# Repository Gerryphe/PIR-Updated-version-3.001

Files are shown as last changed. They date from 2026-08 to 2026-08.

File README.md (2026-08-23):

1. install node js (v9.9.0) https://nodejs.org
2. restart pc
3. install gulp. Type in console npm install -g gulp
4. restart pc
5. open console in project folder
6. npm i - install all modules from package.json
7. index.js file from project foder copy to node_modules\gulp-filelist\
8. gulp clean - clr destination folder
9. gulp build - build project 
10. gulp buildGz - build project with Gzip compression 
11. dest folder - compressed web interface
11. dest\bin folder - binary files for mcu
12. dest\bin\http_serv_fse.cpp - copy this file to project folder, contains all web interface

1. install node js (v10.1.0) https://nodejs.org
2. restart pc
3. install gulp. Type in console npm install -g gulp
4. restart pc
5. open console in project folder
6. npm i - install all modules from package.json
7. index.js file from project foder copy to node_modules\gulp-filelist\
8. gulp clean - clr destination folder
9. gulp build - build project 
10. gulp buildGz - build project with Gzip compression 
11. dest folder - compressed web interface
11. dest\bin folder - binary files for mcu
12. dest\bin\http_serv_fse.cpp - copy this file to project folder, contains all web interface

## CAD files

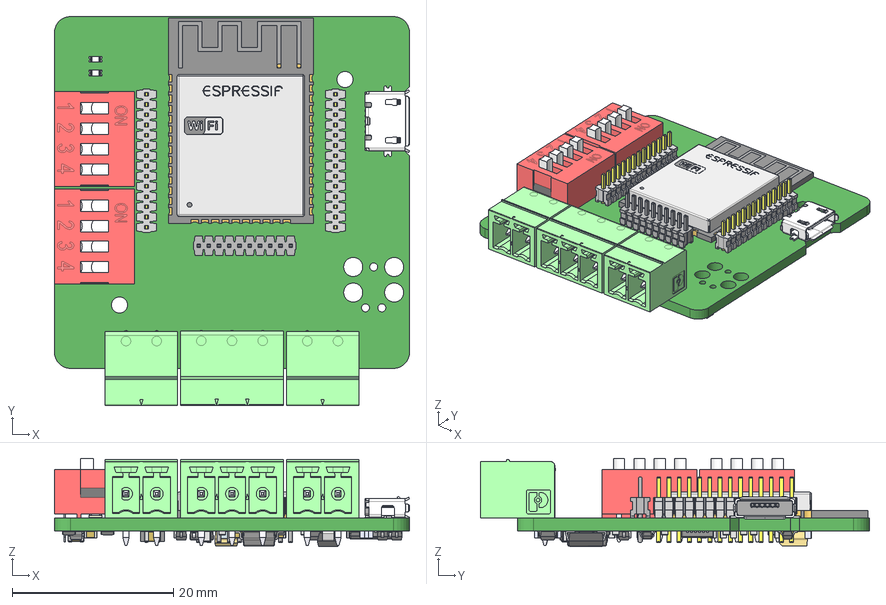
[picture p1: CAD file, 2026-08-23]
1-10VPIR_V1.0/1-10V_PIR_V1.0.step
44.1 x 48.3 x 11.0 mm
T-1M6-10-02-S
TMS-110-S_header
pcb
pads
antenna
logo
SW3dPS-SOD-323 x 4
USB3085-HOUSING
USB3085-SHELL
cap0805 2x1.25x1.35 x 3
User Library-RES_0603L_RES_0603_Lead_1 x 50
User Library-RES_0603L_RES_0603_Body_1 x 25
SW3dPS-LED SMD0603 x 2
T-1M6-14-02-S x 2
TMS-114-S_header x 2
Notch
Silicon Lab Logo Yury
PinsArrayL
PinsArrayR
BODY_MF06A
LEAD_MF06A x 6
User Library-sot143
SW3dPS-Maxim_SOIC8
DS-4 x 2
BAT54 x 2
Pins
BLM18AG601SN1D
0ZCJ0010FF2E--3DModel-STEP-56544
DO-214AC (SMA)
cap0603 1.6x0.8x0.9 x 13
Tant cap CaseB_3528-21

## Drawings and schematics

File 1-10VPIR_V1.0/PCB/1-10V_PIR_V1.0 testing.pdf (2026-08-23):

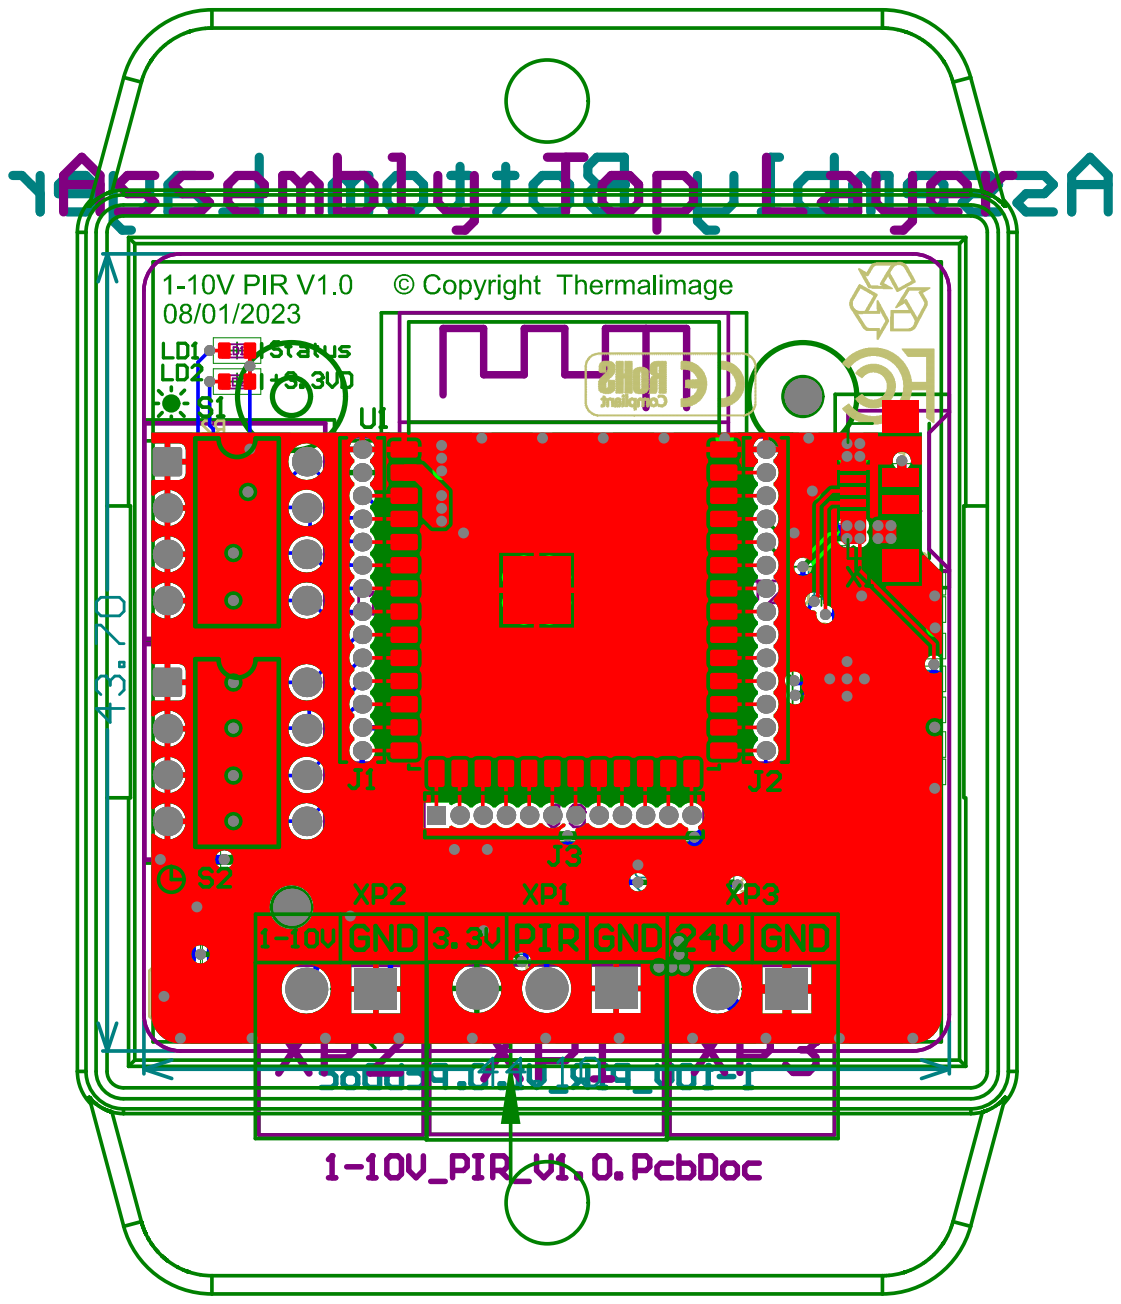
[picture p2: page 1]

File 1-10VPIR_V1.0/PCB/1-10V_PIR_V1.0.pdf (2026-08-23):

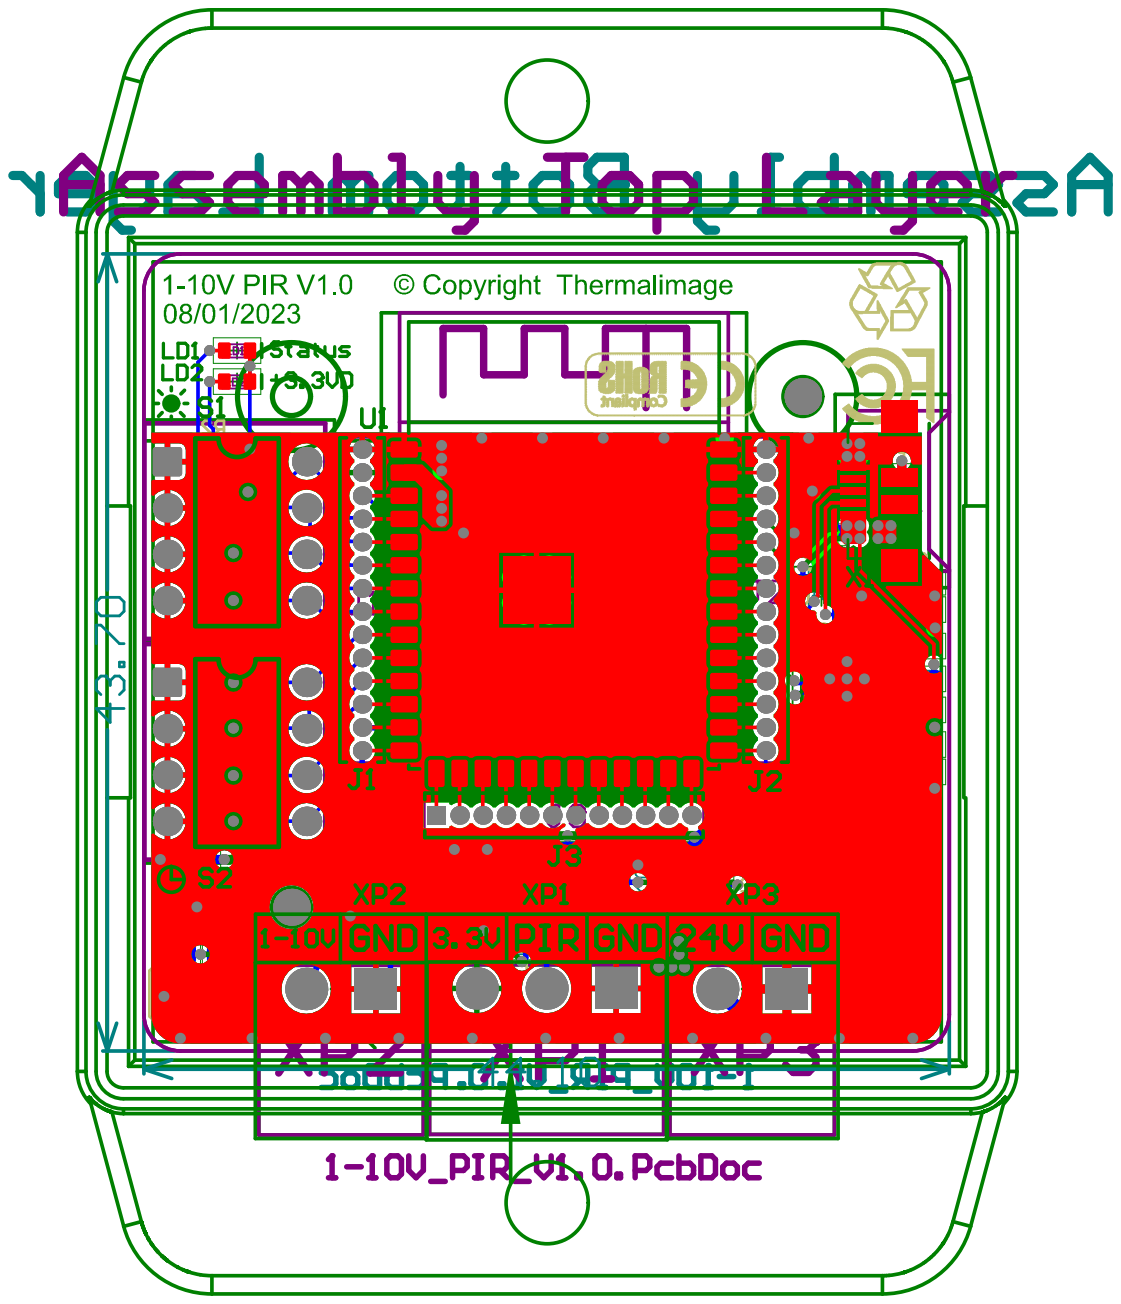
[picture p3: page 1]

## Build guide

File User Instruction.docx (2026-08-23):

# quebec-1-10v-pir

## Introduction

There are two variants of this product one is for prototyping which has the USB to serial chip and can be flash using the USB. The other one is production one that needs tag-connect and programmer. (check, Figs 1,2 and 3)

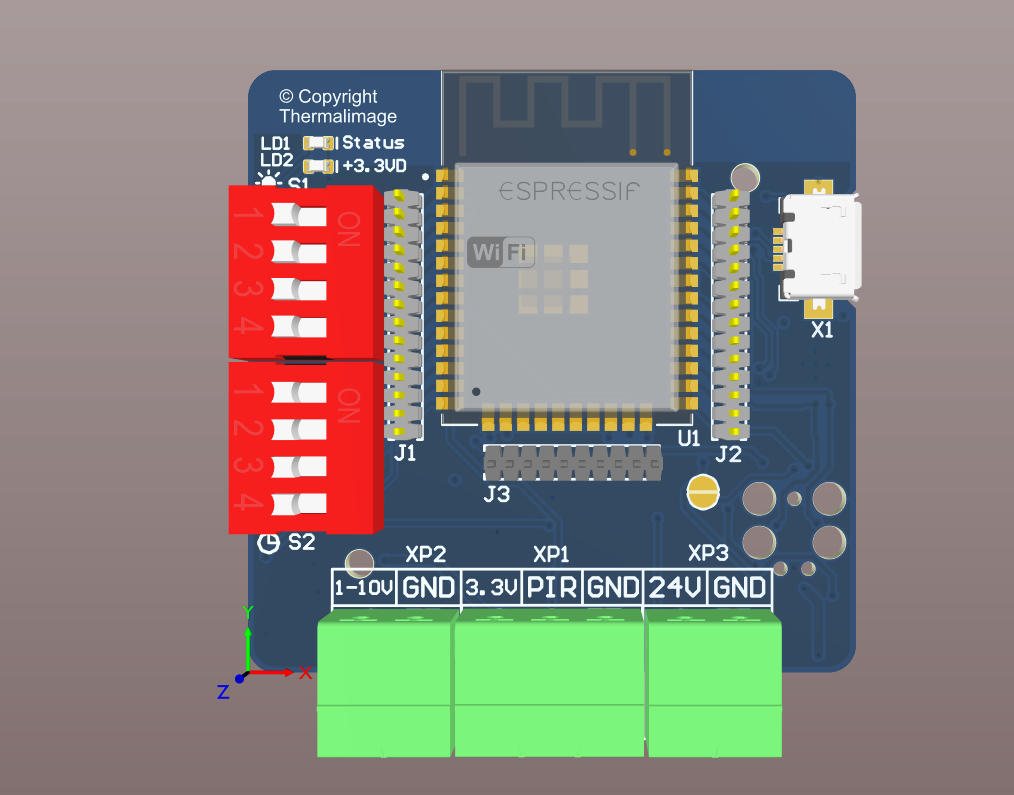
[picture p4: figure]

Figure 1: Top view prototype and Production.

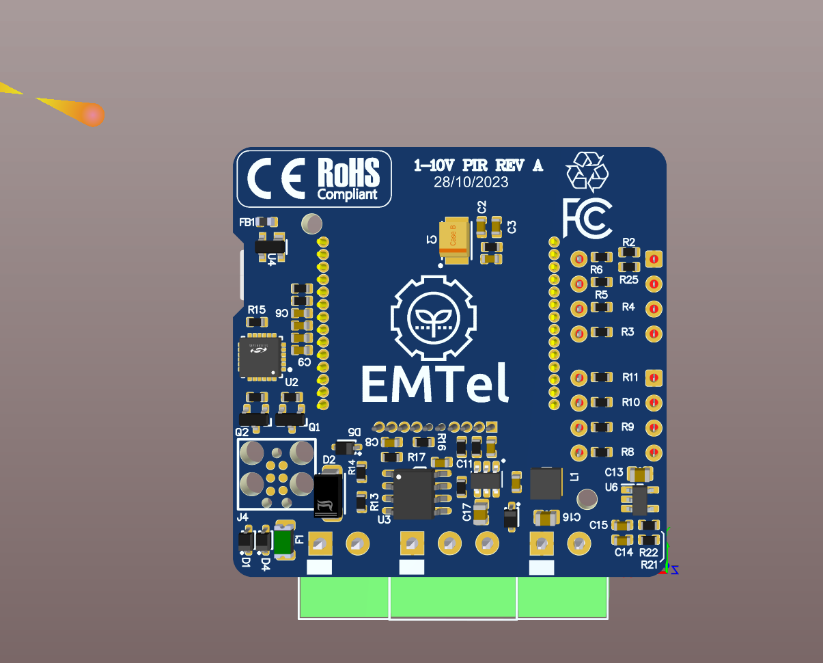
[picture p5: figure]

Figure 2: prototype bottom view.

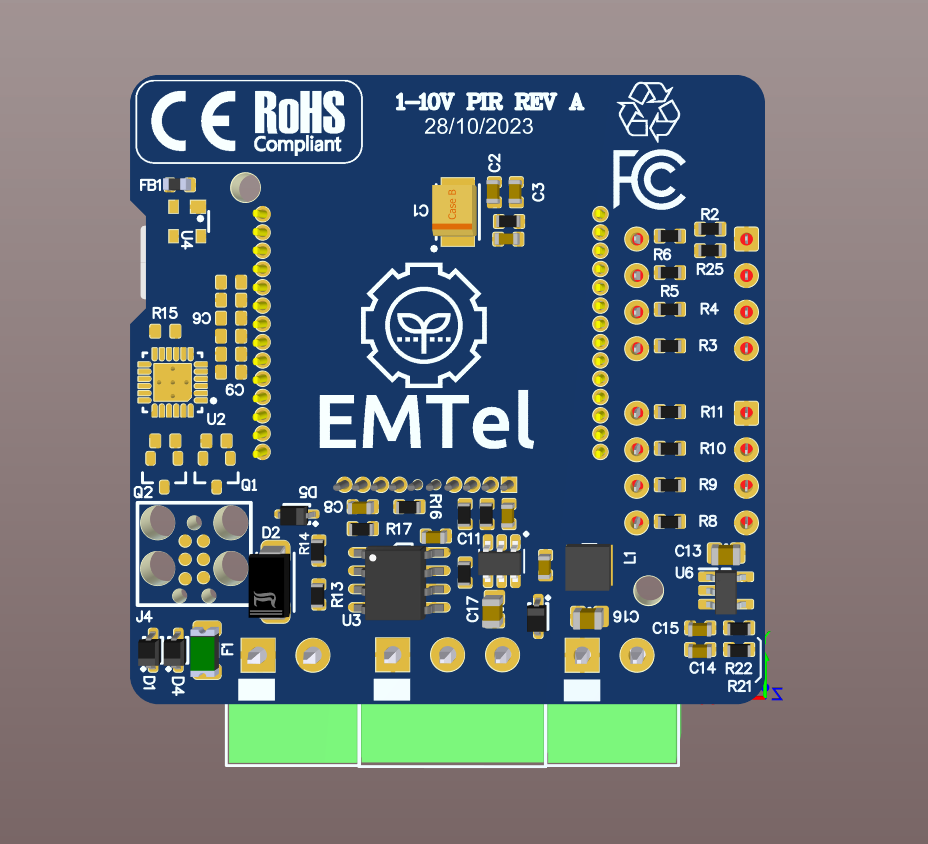
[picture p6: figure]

Figure 3: bottom view of production.

## Connections and Dip switches

There are 2 dip switches on the board for adjusting delay and adjusting dimming.

There is one connector for LED driver, one for PIR sensor and the other one for 24V input, note that the device will power on by USB but for LED driver to work we need 24V input.

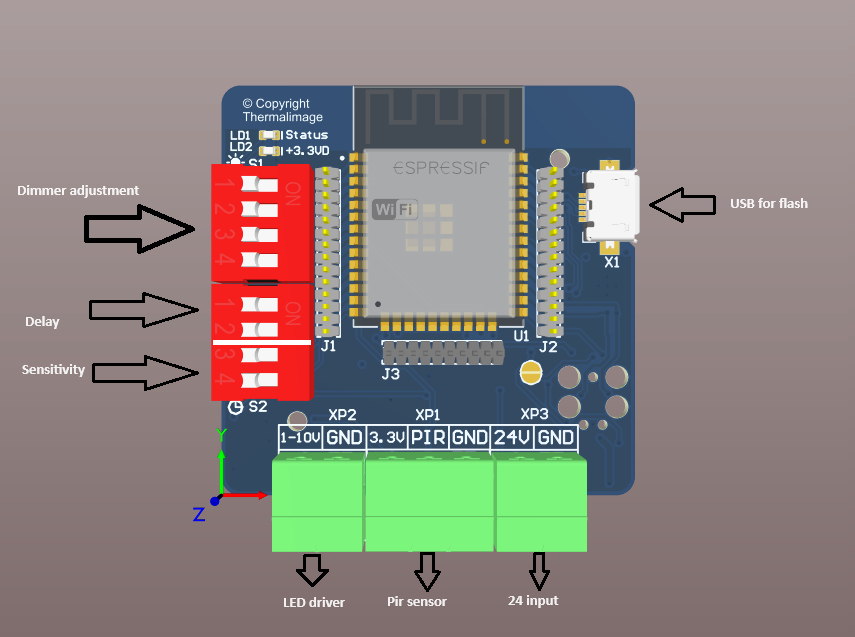
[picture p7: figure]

Figure 4: Connections and dip switch on the board

## Flashing the device (prototype)

Current build is prototype build which does not need tag connect and can be flash directly using USB.

After connecting device to USB, a new serial port (COM port) appear on device manager, the number of appear port can be different (Fig,5 )

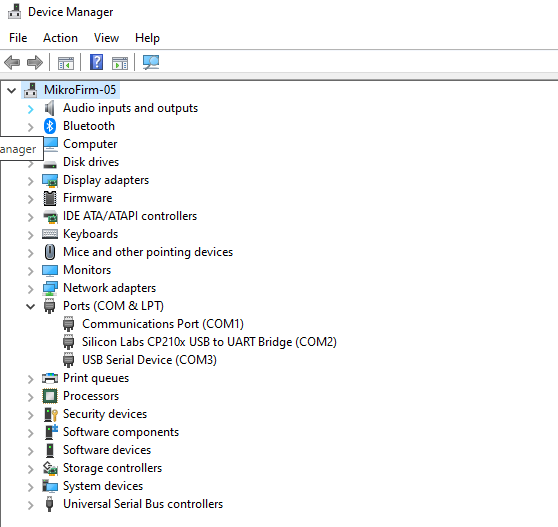
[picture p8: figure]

Figure 5: Silicon Labs CP210x COM2

Now open “flash_download_tool_3.9.5.exe” (from flash folder) and select ESP 32, the following screenshot.

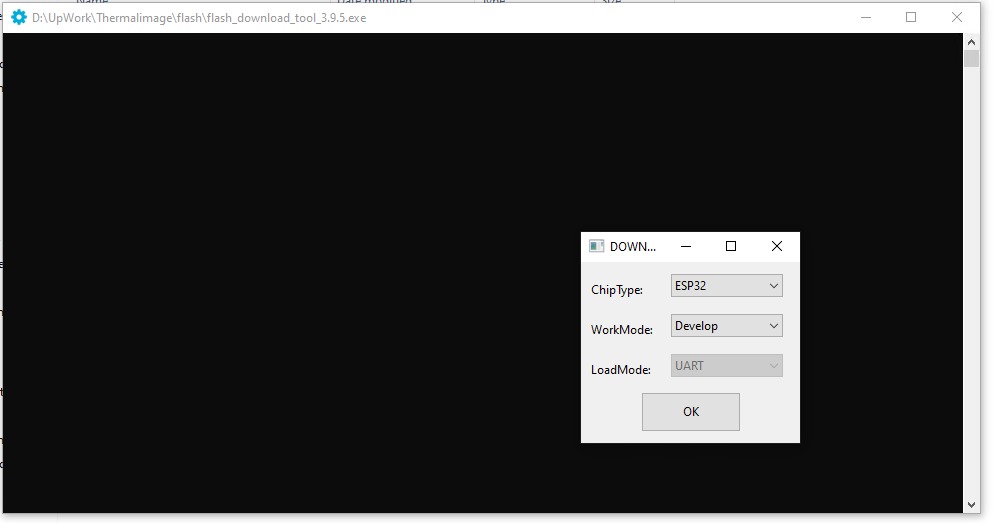
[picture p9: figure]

The set up as the following figure and select right com port.

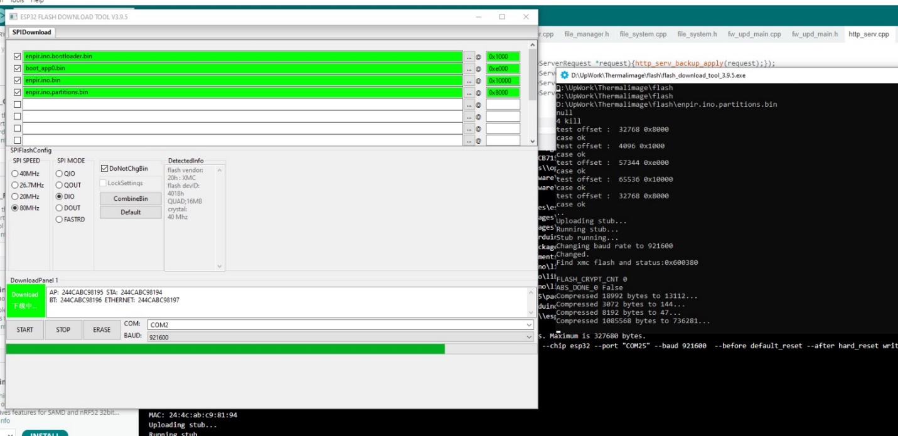
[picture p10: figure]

After flashing follow the these steps.

The first step is to connect to the device.

Devices advertise itself as an access point and name (SSID) is
ENPIR-<mac address>

Password: enco212345

After connection go to a browser and the address is 192.168.1.1

Enter ‘admin’ as username and ‘admin’ as password (Fig, 1).

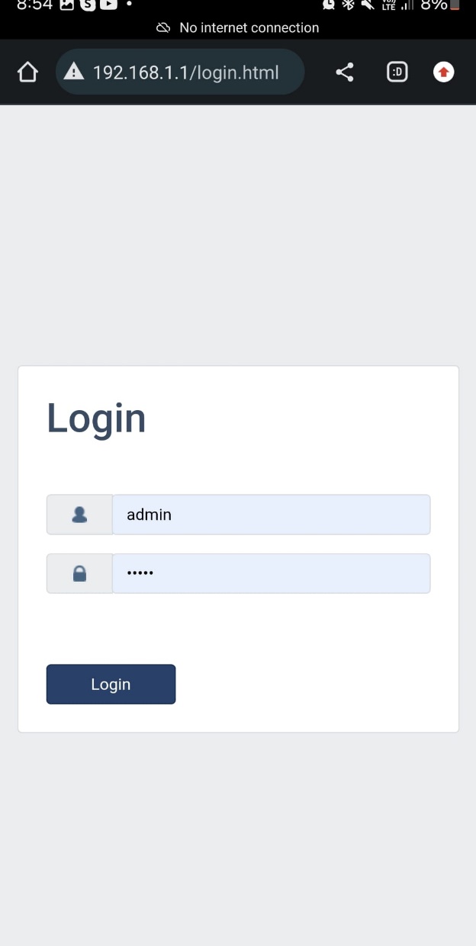
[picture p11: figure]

Figure 6: connect to access point and login.

Then from the hamburger button, select WIFI, enable STA mode and scan for the WIFI SSID and enter the password. After connection you will see the IP address associated to the device by DHCP (Fig,2).

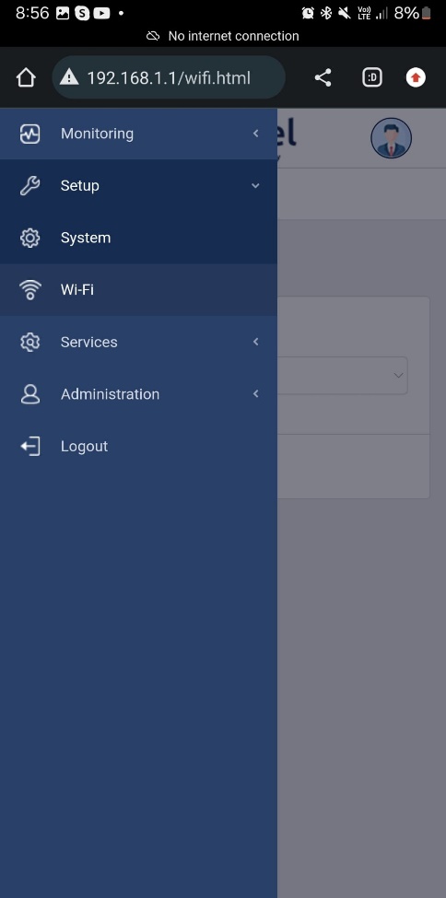
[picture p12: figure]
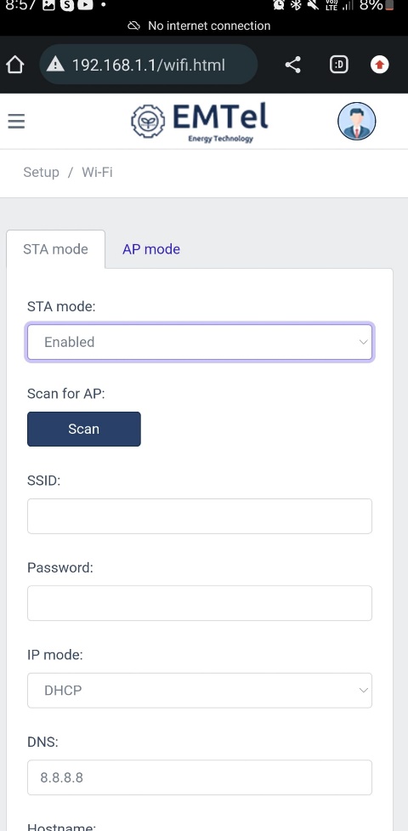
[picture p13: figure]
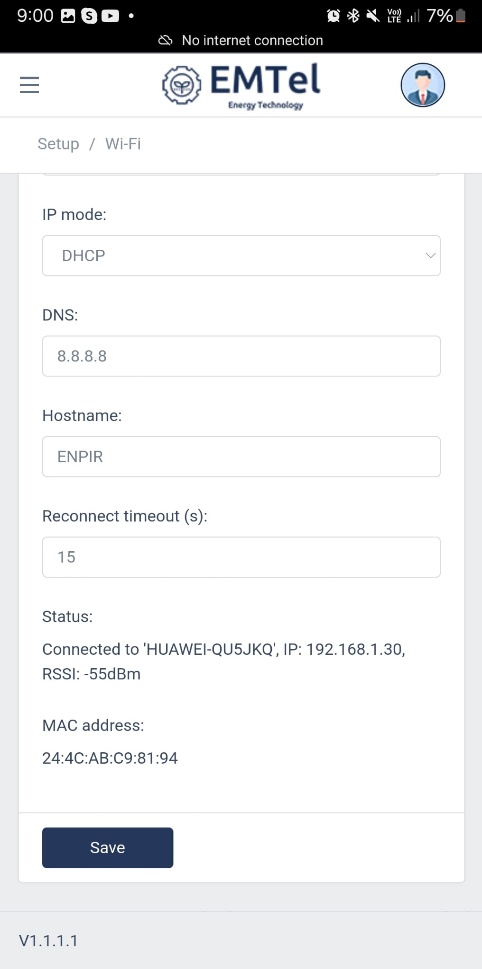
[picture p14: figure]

Figure 7: setup WIFI

Now the device can be accessed using this IP with a computer or a mobile on the same network.

## 1-10 PIR Dimming control Sensor

For setting up the 1-10, please go to setup/system and enable Display and by default it shows 25 to 100, and other values can be selected by using dip switch on the board.

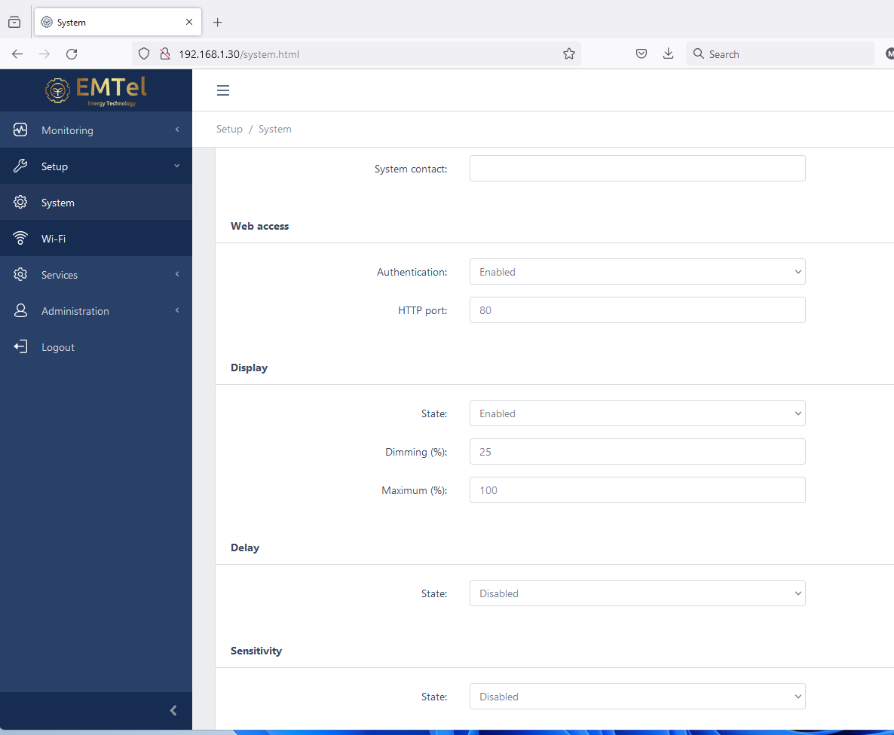
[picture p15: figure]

When the device triggers (PIR sensor activated) the voltage level of driver goes to the maximum that is setup in the web UI considering the position of 4-bit dip switch (refer to Fig 4).

The applied voltage value is based on the diffidence between maximum and minimum, divided by dip switch value

Example:

Maximum: 100% (10V)

Minimum: 25% (2.5V)

(S1) 4-bit dip position (1,2,3,4) 1111 (see Fig, 8)

The applied value will be 10V during activation.

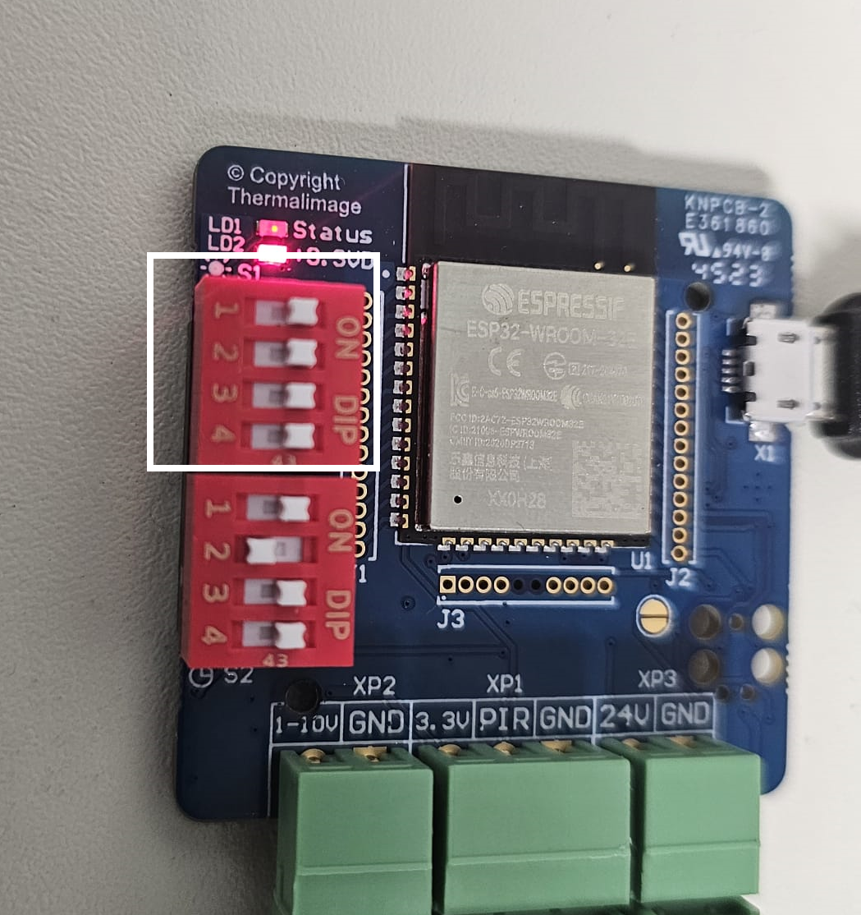
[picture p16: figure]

Figure 8: Position of dip switch for 1111

(S1) 4-bit dip position (1,2,3,4) 0000

The applied value will be same as minimum during activation.

S1) 4-bit dip position (1,2,3,4) XXXX (see Fig, 8)

XXXX should be turned to binary.

The applied value will be same as minimum + 1/15 (maximum – minimum)x(XXXX) during activation.

Note 1: that if the delay disabled the output of LED driver will be 0.

Note 2: The minimum dim allowed is 10% and the minimum and maximum should have at least 20% difference.

Connect the LED driver and test.

## 1-10 PIR delay

When the delay is enabled, after activation and deactivation timer will start.

If all delay switch is on 11 it is full delay set in the web portal and if

XX the results

(XX+1)/4 x (time set in the web portal).

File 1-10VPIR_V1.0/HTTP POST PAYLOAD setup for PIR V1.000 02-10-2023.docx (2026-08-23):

{

"Monitor":{

"DeviceInfo":{

"DeviceMod":"PIR-V1.000",

"DeviceName":"As per name input in setup",

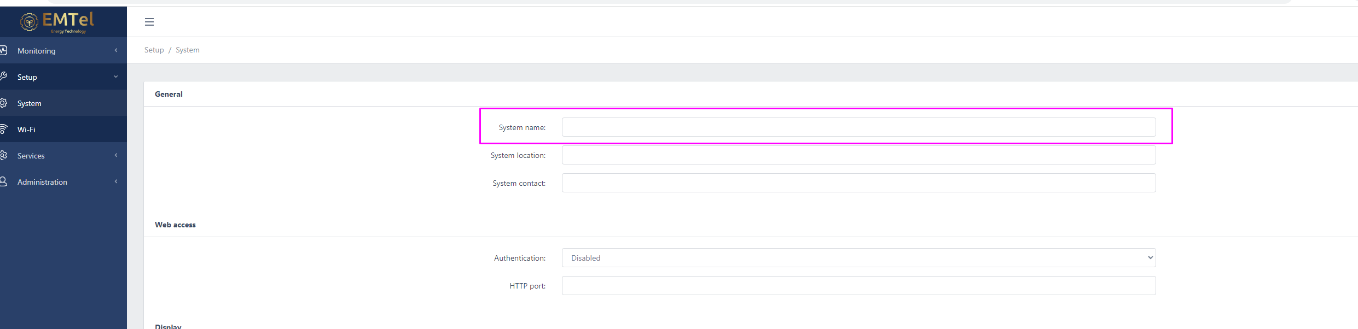
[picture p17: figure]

"ID":"24:0A:C4:AF:DF:98", we need to be able to assign our own mac id

"MainAppVer":"1.1.1.1", from the device

"MainBootVer":"1.1.1.1", from the device

"WiFi":{

"Ver":"1.3.5.8", from the device

"AP":{

"MAC":"24:0A:C4:AF:DF:99",

"State":1,

"Signal":19.5

},

"STA":{

"MAC":"24:0A:C4:AF:DF:98",

"State":1,

"Signal":-40

}

}

},

"CH":{

"CH1":{

"status":0, enabled = 1 or disabled = 0

"description":"Max Output",

"MO":100, As per setup This is in %

},

"CH2":{

"status":0, enabled = 1 or disabled = 0

"description":"Dimming",

"DI":25, As per setup this is in %

"DC":96, counter of cycles

"DA":0, dimming active = 1 dimming in standby = 0

},

"CH3":{

"status":0, enabled = 1 or disabled = 0

"description":"Time Out",

"TO":20, As per setup this is displayed in min

},

"CH4":{

"status":0, enabled = 1 or disabled = 0

"description":"Sensitivity",

"SY":85,As per setup This is in %

"SC":445, counter of cycles

},

"Time":{

"ts":946686273

}

}

}

ts - timestamp in unix format.

There should be four settings for the user inputs

By default, these should all be on and the following be the defaults

Max output: 100%

Dimming: 25%

Time out: 20 mins

Sensitivity: 100%

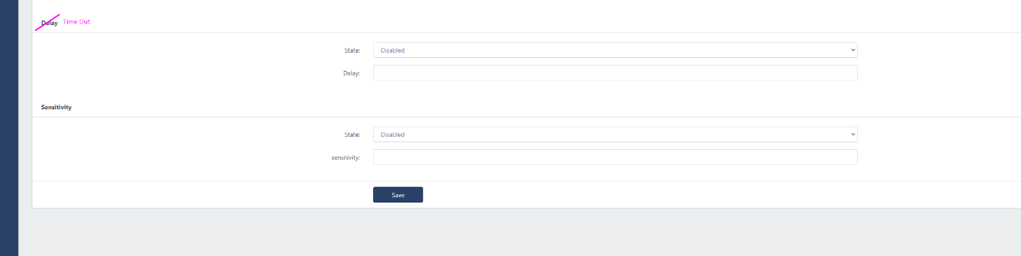
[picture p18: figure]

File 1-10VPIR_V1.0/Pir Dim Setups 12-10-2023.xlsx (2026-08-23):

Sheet: Sheet1
PIR Dimming Pin Setup and how it works |  |  |  |  |  |  |  |  |  |  | 40w driver |  |  | 80w Driver
 |  | Default setting | Pin setups |  |  |  |  |  |  |  | 24
 | Max Output | 100% |  |  |  |  | Output | Difference |  | ma | watts |  | ma | watts | %
 | Dimming | 25% | 0 | 0 | 0 | 0 | 25.00% | 0.00% | Default | 0.442 | 10.608 | 44.20% | 0.916 | 21.984 | 91.60%
 |  |  | 0 | 0 | 0 | 1 | 30.00% | 5.00% |  | 0.968 | 23.232 | 96.80% | 0.918 | 22.032 | 91.80%
 |  |  | 0 | 0 | 1 | 0 | 35.00% | 5.00% |  | 0.795 | 19.08 | 79.50% | 0.919 | 22.056 | 91.90%
 |  |  | 0 | 0 | 1 | 1 | 40.00% | 5.00% |  | 0.968 | 23.232 | 96.80% |  | 0 | 0.00%
 |  |  | 0 | 1 | 0 | 0 | 45.00% | 5.00% |  | 0.62 | 14.88 | 62.00% |  | 0 | 0.00%
 |  |  | 0 | 1 | 0 | 1 | 50.00% | 5.00% |  | 0.99 | 23.76 | 99.00% |  | 0 | 0.00%
 |  |  | 0 | 1 | 1 | 0 | 55.00% | 5.00% |  | 0.971 | 23.304 | 97.10% |  | 0 | 0.00%
 |  |  | 0 | 1 | 1 | 1 | 60.00% | 5.00% |  | 0.996 | 23.904 | 99.60% |  | 0 | 0.00%
 |  |  | 1 | 0 | 0 | 0 | 65.00% | 5.00% |  | 0.53 | 12.72 | 53.00% |  | 0 | 0.00%
 |  |  | 1 | 0 | 0 | 1 | 70.00% | 5.00% |  | 0.989 | 23.736 | 98.90% |  | 0 | 0.00%
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

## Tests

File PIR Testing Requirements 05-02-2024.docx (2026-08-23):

Pir Testing Requirements 05-05-2024

All of the functions of the pir sensor must be tested and the results noted down and filed into the OneDrive folder

There need to be a technical data sheet made for the sensor complete with all of the details for the technical requirements including the compliance details and references.

There needs to be a user instruction sheet setting out all connections with explanation of function and connections

There need to be a web browser user and configuration instruction sheet

Board and function tests:

1. Test for the input voltage lowest-highest and check for any sign of heat
2. Test and note the device consumption in mv
3. Test the leds and note the sequence, colour and functions are correct
4. Test the dimming dips and there outputs in line with the settings and table below

PIR Dimming Pin Setup and how it works
| | Default setting | | Pin setups
| Max Output | 80% | | | | | | Output | Difference
| Dimming | 25% | | 0 | 0 | 0 | 0 | 25.00% | 0.00% | Default
| | | | 0 | 0 | 0 | 1 | 28.67% | 3.67%
| | | | 0 | 0 | 1 | 0 | 32.33% | 3.67%
| | | | 0 | 0 | 1 | 1 | 36.00% | 3.67%
| | | | 0 | 1 | 0 | 0 | 39.67% | 3.67%
| | | | 0 | 1 | 0 | 1 | 43.33% | 3.67%
| | | | 0 | 1 | 1 | 0 | 47.00% | 3.67%
| | | | 0 | 1 | 1 | 1 | 50.67% | 3.67%
| | | | 1 | 0 | 0 | 0 | 54.33% | 3.67%
| | | | 1 | 0 | 0 | 1 | 58.00% | 3.67%
| | | | 1 | 0 | 1 | 0 | 61.67% | 3.67%
| | | | 1 | 0 | 1 | 1 | 65.33% | 3.67%
| | | | 1 | 1 | 0 | 0 | 69.00% | 3.67%
| | | | 1 | 1 | 0 | 1 | 72.67% | 3.67%
| | | | 1 | 1 | 1 | 0 | 76.33% | 3.67%
| | | | 1 | 1 | 1 | 1 | 80.00% | 3.67% | Max
| Pin variant | 55%

Date | 04/03/2023 | 1-10 Dimming control Sensor Output Setup for WEB
| | Select Config value By user input cell
| Dip Setup No. | 100 | 90 | 80 | 70 | 60 | 50 | 40 | 30 | 20 | 10
| 1 | 100% | 90.0% | 81.0% | 72.9% | 65.6% | 59.0% | 53.1% | 47.8% | 43.0% | 38.7%
| 2 | 92% | 82.8% | 74.5% | 67.1% | 60.4% | 54.3% | 48.9% | 44.0% | 39.6% | 35.6%
| 3 | 84% | 75.6% | 68.0% | 61.2% | 55.1% | 49.6% | 44.6% | 40.2% | 36.2% | 32.5%
| 4 | 76% | 68.4% | 61.6% | 55.4% | 49.9% | 44.9% | 40.4% | 36.4% | 32.7% | 29.4%
| 5 | 68% | 61.2% | 55.1% | 49.6% | 44.6% | 40.2% | 36.1% | 32.5% | 29.3% | 26.3%
| 6 | 60% | 54.0% | 48.6% | 43.7% | 39.4% | 35.4% | 31.9% | 28.7% | 25.8% | 23.2%
| 7 | 52% | 46.8% | 42.1% | 37.9% | 34.1% | 30.7% | 27.6% | 24.9% | 22.4% | 20.1%
| 8 | 44% | 39.6% | 35.6% | 32.1% | 28.9% | 26.0% | 23.4% | 21.0% | 18.9% | 17.0%
| 9 | 36% | 32.4% | 29.2% | 26.2% | 23.6% | 21.3% | 19.1% | 17.2% | 15.5% | 13.9%
Fixed Min output | 10 | 10% | 10% | 10% | 10% | 10% | 10% | 10% | 10% | 10% | 10%

5. Connect, Test and note the sensor connections from the pir and add a drawing to show connections from the sensor identifying the pinouts to the connections on the board and test in Realtime with a 1-10v driver and led light.
6. Test the time out setting are working and relative to the dip setups and web configurations
7. Test the sensitivity functions and note the results.
8. Test the USB functions and note the results
9. Test the wifi and mesh the three devices together and note the results and check the configuration is correct.
10. Test the web application functions in remote and usb mode and note the results .
11. Test the push functions and data string

Web App:

1. Monitoring Page:
  a. Make sure the data is displaying the correct information and that the memory is running in circular sequence so that the device cannot hang and the oldest data over writes first when its reaching the capacity, this should upload all the data once reconnection is established.
2. Setup/System:
  a. Set the device MAC id to Thermalimage one https://maclookup.app/search/vendors/result?vendor=thermalimage

Vendor (https://maclookup.app/macaddress/7c83340)

Details (https://maclookup.app/macaddress/7c83340/mac-address-details)

OUI: 7C:83:34:0

Range: 7C:83:34:00:00:00 - 7C:83:34:0F:FF:FF

Block Size: 1048575 (1.04 M)

Universally administered addresses (UAA) : the address is uniquely assigned by its manufacturer.

Type of transmission: Unicast

  b. General Setup and confirm it then applies and is attached into the sending string
  c. Web Access configuration
  d. Display settings title change to Light level and test it then applies and is attached into the sending string
  e. Delay Settings title change to Dimming Timeout and test it then applies and is attached into the sending string
  f. Sensitivity setup and check and test it then applies and is attached into the sending string
4. System/WiFi:
  a. STA mode configuration and functions.
  b. AP Mode configuration and functions.
  c. Mesh functions
  d. Hide the network name from being seen to the public tab
5. Services/Push/NTP
  a. Setup for http/https setup and push function and testing the data is sending in the string
  b. Urls for to capture settings on the local machine and read to outgoing messages in parallel
  c. NTP setup and auto scanning functions
6. Administration:
  a. User setups access and functions, check they store on the device memory and don’t get lost during a power loss and are auto recalled when repowered
  b. Backup functions, check the original version of firmware is stored and the tab to factory reset works.
  c. Check that configurations and settings store correctly and don’t get lost during a power loss and are auto recalled when repowered
  d. Check that the firmware update setup works correctly and that the board can be updated OTA and reboots correctly and is fully accessible OTA after update

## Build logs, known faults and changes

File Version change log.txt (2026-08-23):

Version 1.1.1.2
** updates
* LED driver is implemented 
  - when enable in the web portal it goes to a value determine with difference between MIN and MAX on web portal and value of dip-switch 1
* delay is implemented 
  - the delay time determine with the value set on the web portal and dip-switch position
** bug fixed
* web portal logout bug is fixed

Version 1.1.1.3
* Logger added

Version 1.1.1.4
* config can be changed using Rest API using host IP
* ST_LED blinking during dimming and solid during activation
* Display to Dimming

Version 1.1.1.5

* default values added 
  set to 25% and 100% for dimming

* 100 second for delay
* sensitivity 100%
* change value for ntp time out to 5 second (to set the time correctly)
* dimming maximum changes will affect immediately.

Version 1.1.1.6
* fading added for every percent between dimming and maximum take 20ms

Version 1.1.1.7
* timeout bug fixed ( the maximum was limited to 255s now it can be more 8bit now it 16 bit)

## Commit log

2026-08-23 Create 1-10VPIR_V1.0 Case.zip
2026-08-23 Create [1] - MCU.SchDoc
    [[1] - MCU.SchDoc]
2026-08-23 Create Pir Dim Setups 12-10-2023.xlsx
    [Pir Dim Setups 12-10-2023.xlsx]
2026-08-23 Create [2] - PWR.SchDoc
    [[2] - PWR.SchDoc]
